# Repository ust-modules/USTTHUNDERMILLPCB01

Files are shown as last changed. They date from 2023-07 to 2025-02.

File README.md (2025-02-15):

# THUNDERMILL01 stator PCB

The PCB is part of [Electric field mill](https://github.com/UniversalScientificTechnologies/THUNDERMILL01).

<p float="left">
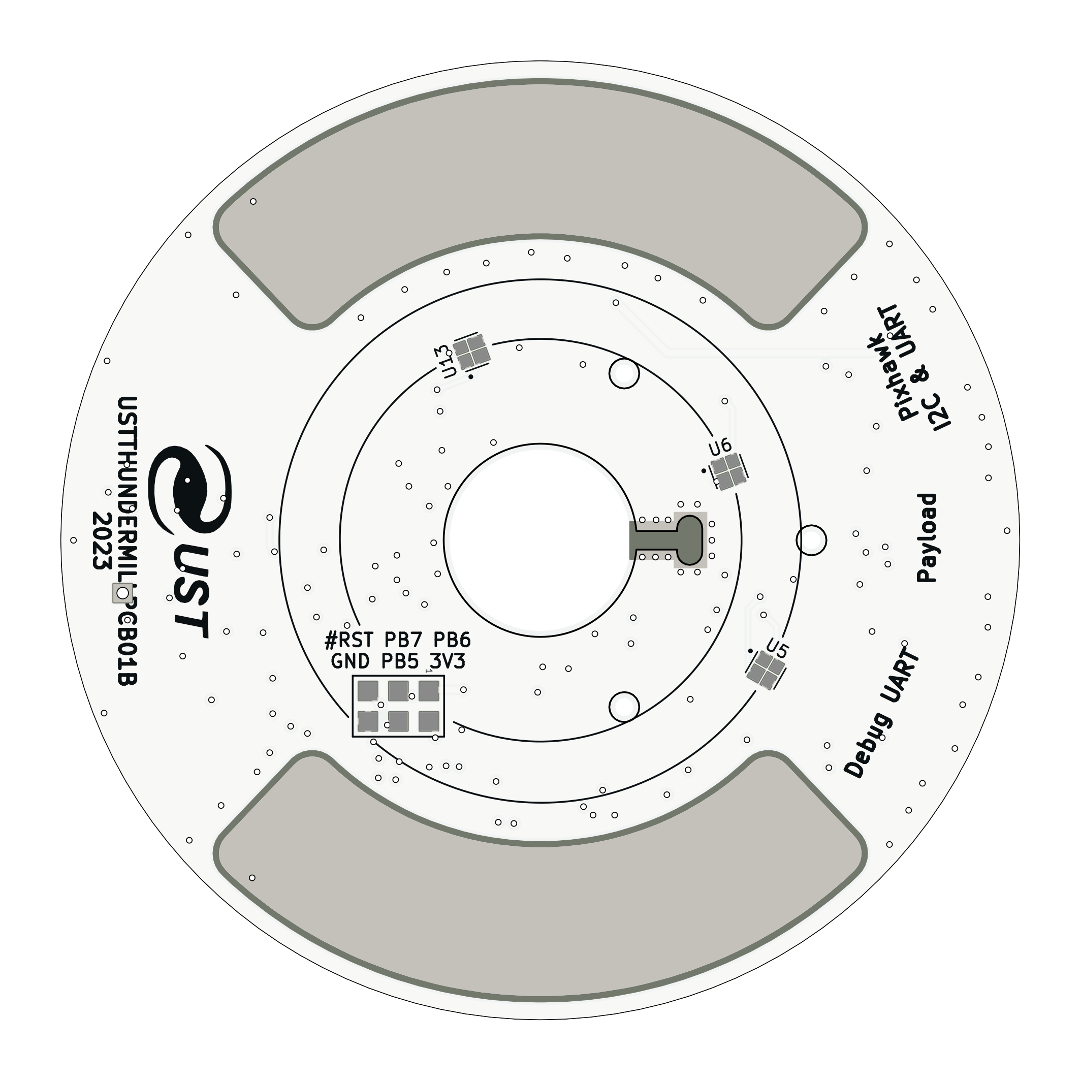
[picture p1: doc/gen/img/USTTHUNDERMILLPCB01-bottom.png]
  
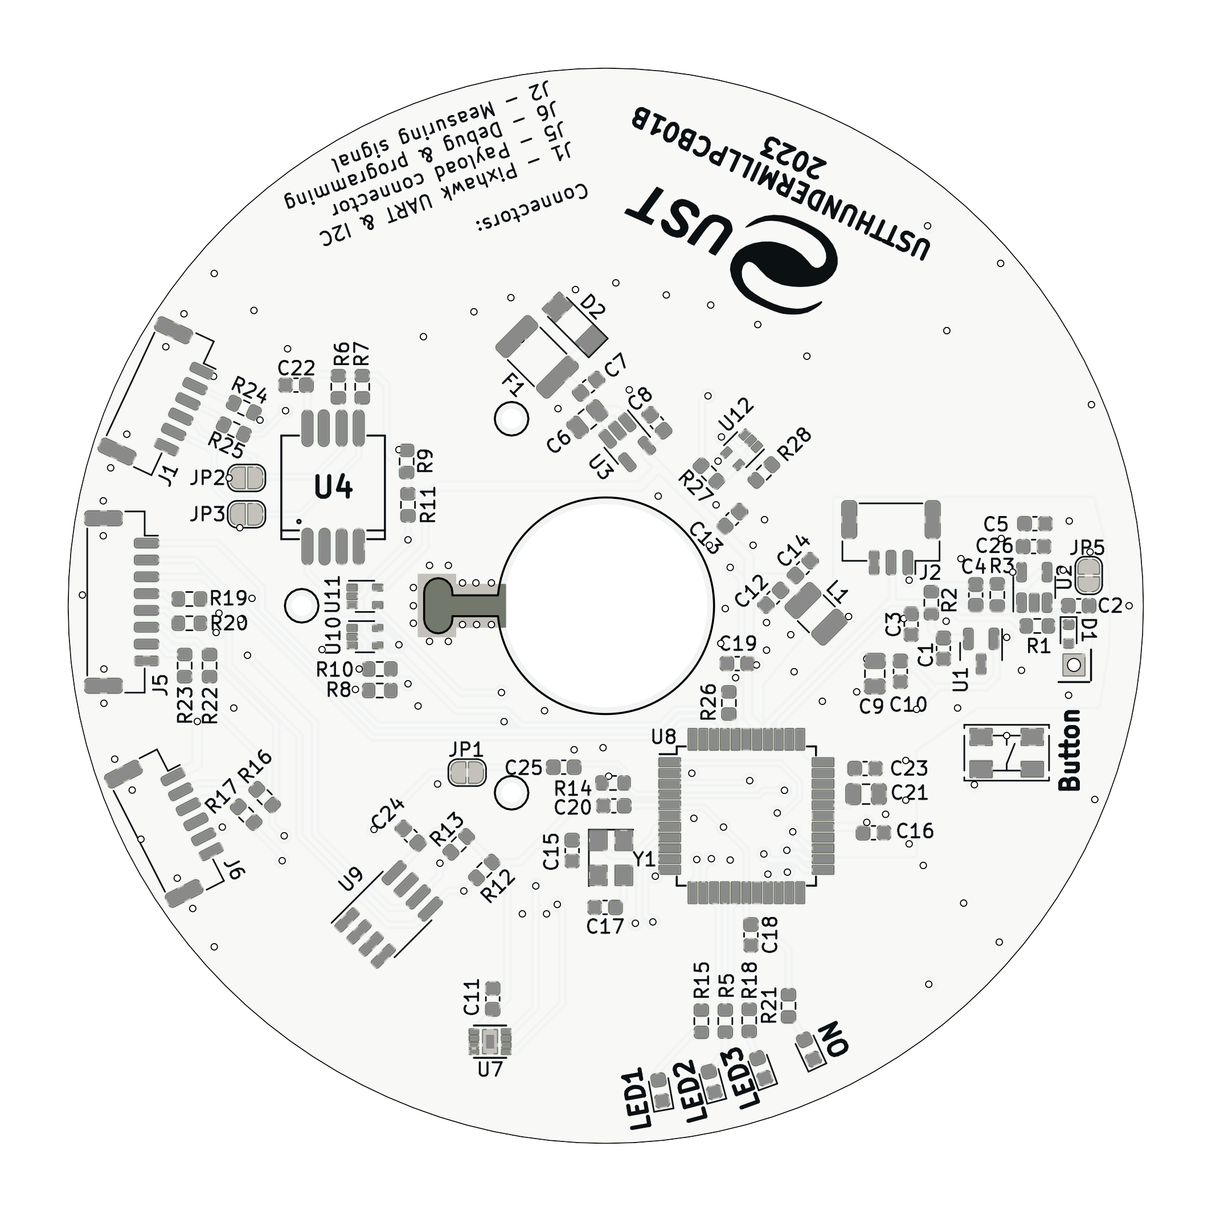
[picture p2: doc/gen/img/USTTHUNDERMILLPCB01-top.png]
   
</p>

The PCB consists analog front end, microcontroller and interface connectors.

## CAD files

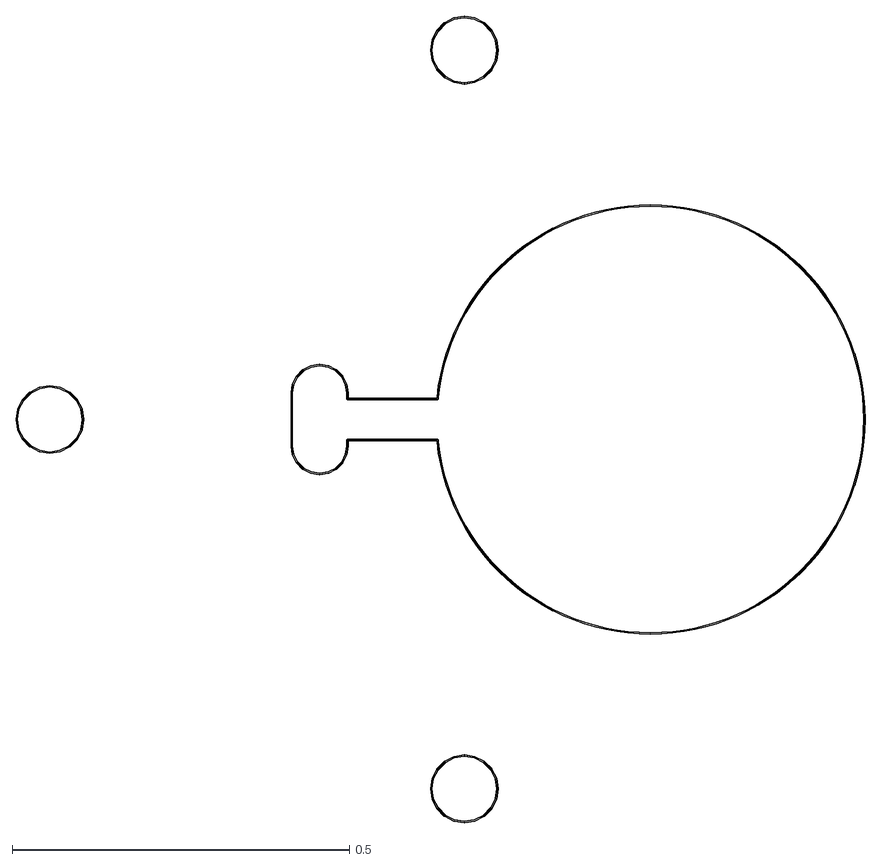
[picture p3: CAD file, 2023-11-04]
doc/gen/dxf/USTTHUNDERMILLPCB01-Edge_Mill.dxf
1.26 x 1.19

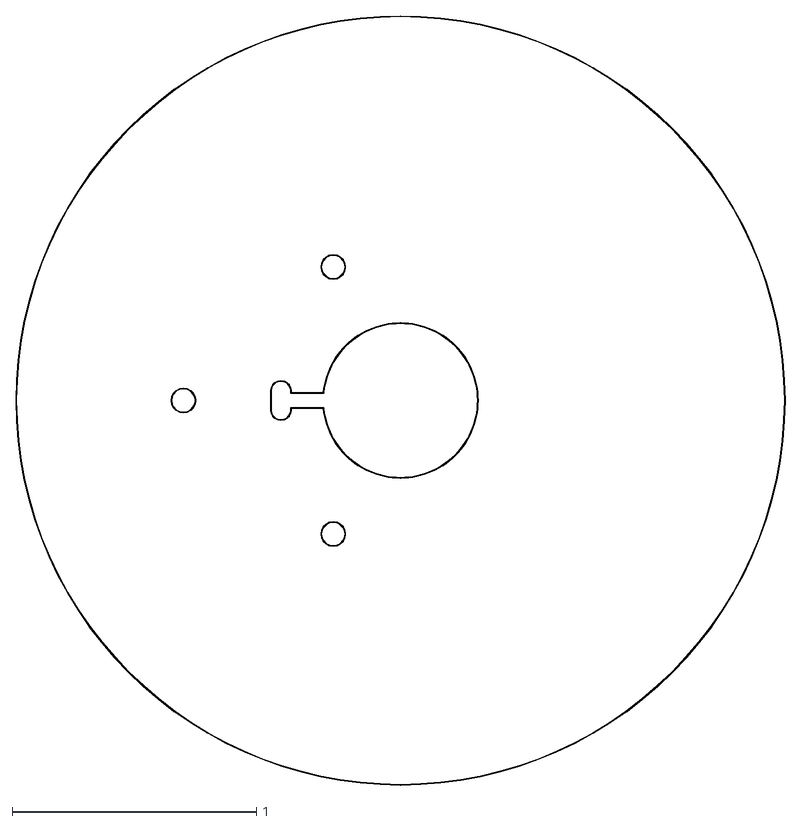
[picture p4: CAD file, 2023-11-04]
doc/gen/dxf/USTTHUNDERMILLPCB01-Edge_Cuts.dxf
3.15 x 3.15

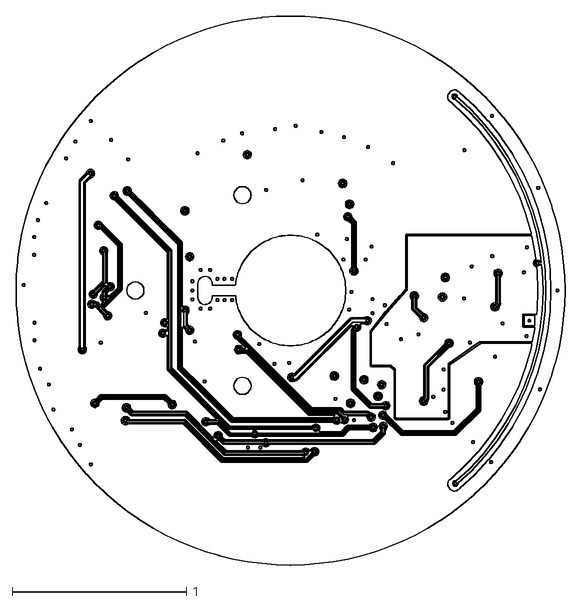
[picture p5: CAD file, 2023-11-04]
doc/gen/dxf/USTTHUNDERMILLPCB01-In1_Cu.dxf
3.15 x 3.15

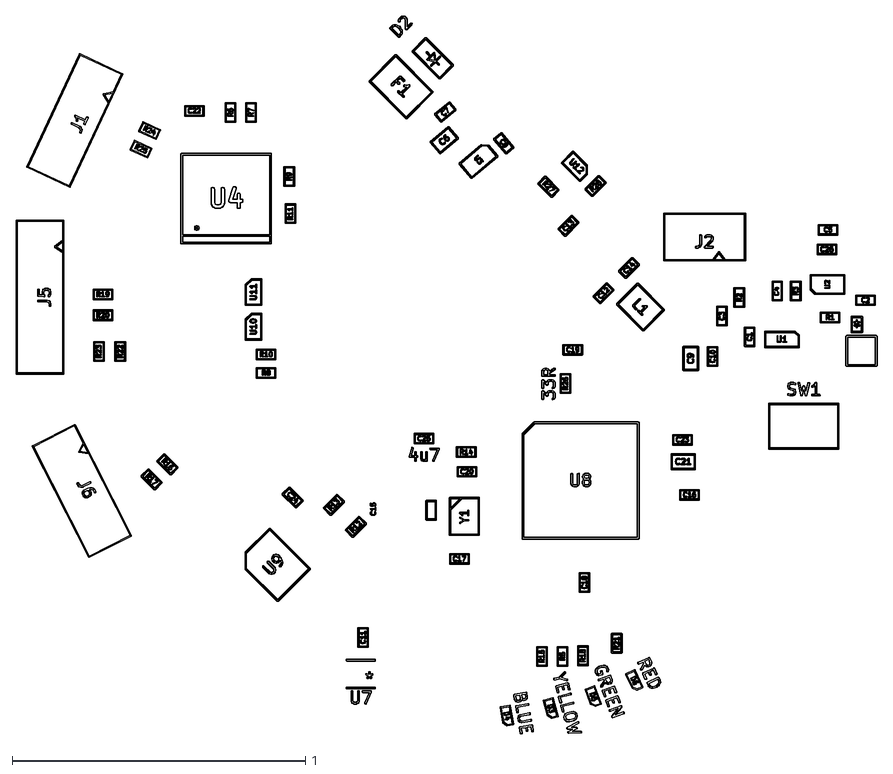
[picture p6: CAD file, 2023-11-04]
doc/gen/dxf/USTTHUNDERMILLPCB01-F_Fab.dxf
2.94 x 2.45

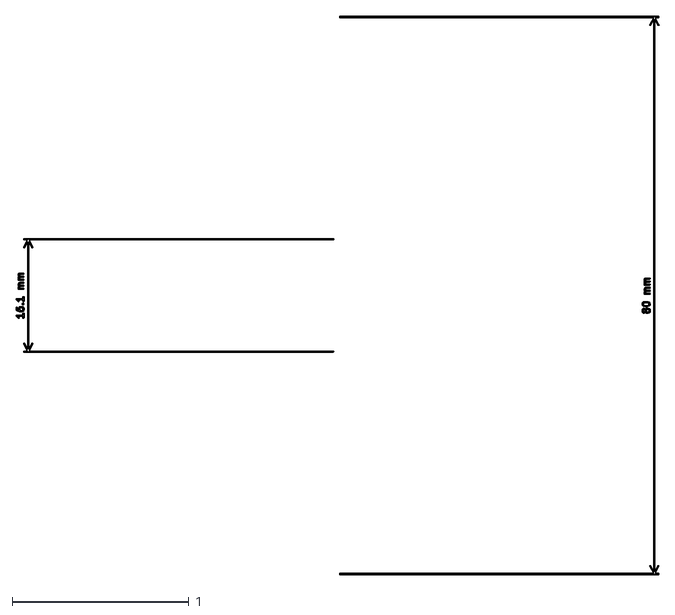
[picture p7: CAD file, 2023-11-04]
doc/gen/dxf/USTTHUNDERMILLPCB01-User_Comments.dxf
3.64 x 3.16

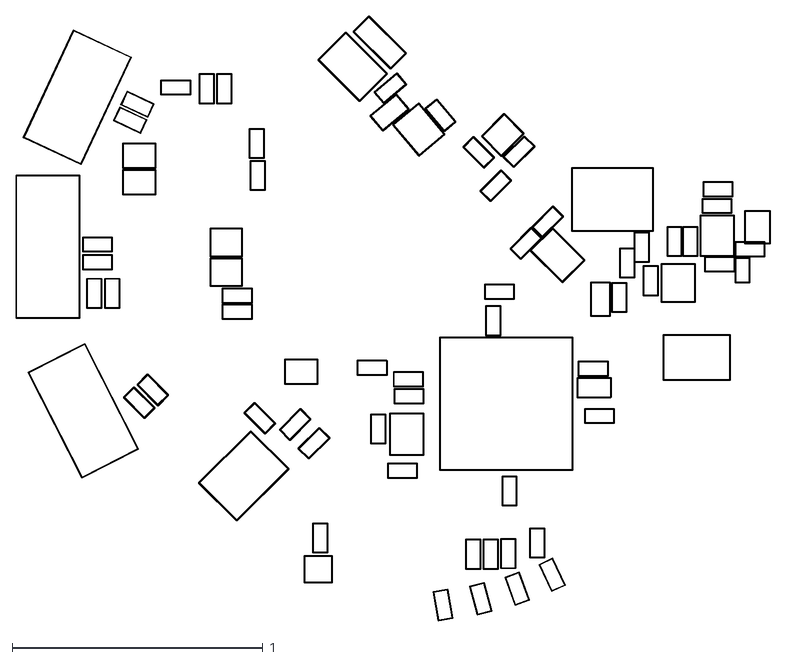
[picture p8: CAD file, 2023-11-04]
doc/gen/dxf/USTTHUNDERMILLPCB01-F_Courtyard.dxf
3.01 x 2.41

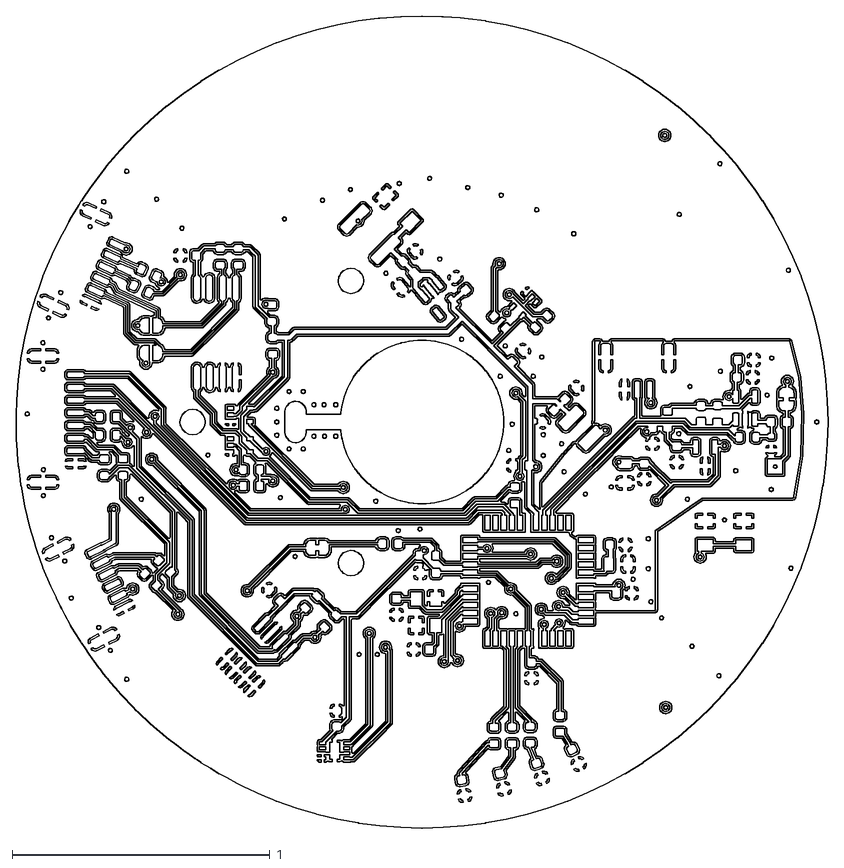
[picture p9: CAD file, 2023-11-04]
doc/gen/dxf/USTTHUNDERMILLPCB01-F_Cu.dxf
3.15 x 3.15

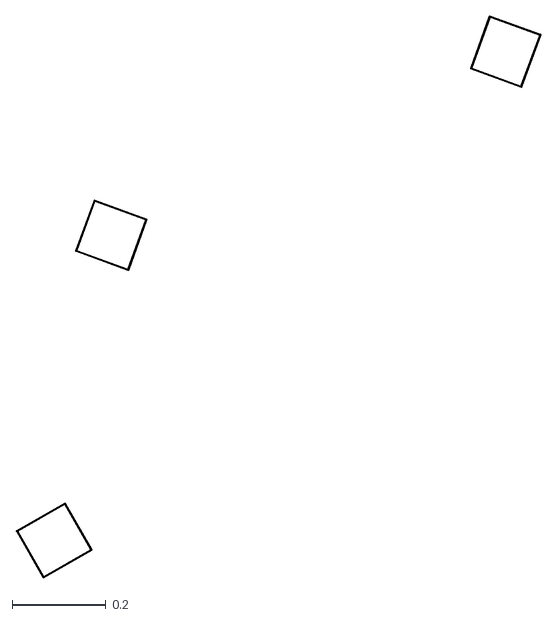
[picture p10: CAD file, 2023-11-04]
doc/gen/dxf/USTTHUNDERMILLPCB01-B_Courtyard.dxf
1.12 x 1.20

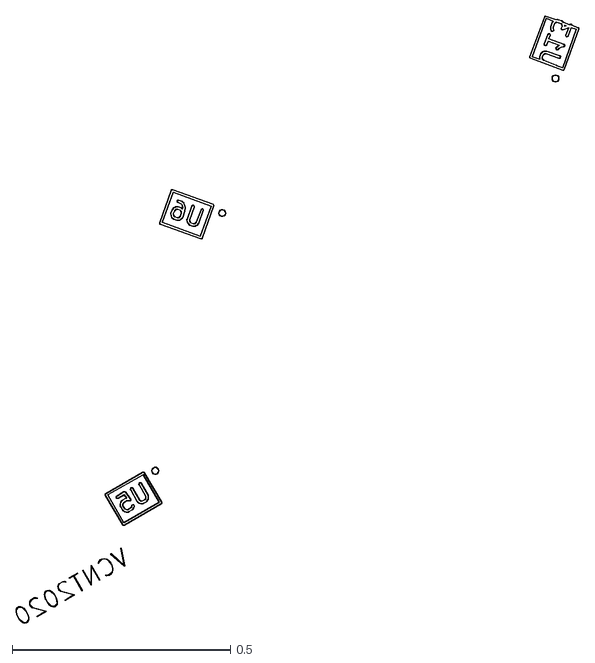
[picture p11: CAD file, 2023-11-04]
doc/gen/dxf/USTTHUNDERMILLPCB01-B_Fab.dxf
1.29 x 1.39

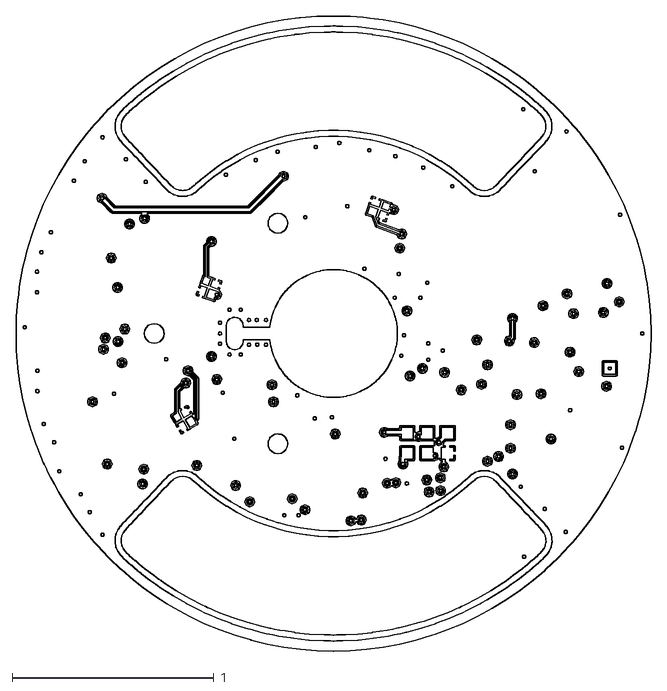
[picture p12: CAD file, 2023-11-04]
doc/gen/dxf/USTTHUNDERMILLPCB01-B_Cu.dxf
3.15 x 3.15

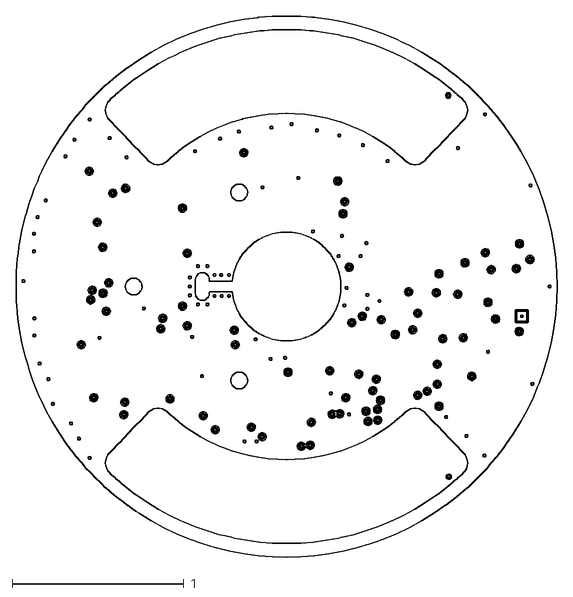
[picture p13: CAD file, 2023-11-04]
doc/gen/dxf/USTTHUNDERMILLPCB01-In2_Cu.dxf
3.15 x 3.15

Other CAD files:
doc/gen/dxf/USTTHUNDERMILLPCB01-B_Silkscreen.dxf
doc/gen/dxf/USTTHUNDERMILLPCB01-F_Silkscreen.dxf

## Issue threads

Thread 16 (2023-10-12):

Odolnost zarizeni proti vlhkosti

kakl, 2023-10-12:
Odpor R1 kondenzator C2 a D1 by bylo vhodne mit ve velikosti minimalne 805, lepe 1206.
Mely by zde byt take vetsi izolacni vzdalenosti.

Abych mohl snizit sense resistor R1 na 2M2, upravil jsem zesileni z 5,5x na 22x pomoci R2=470.

kakl, 2023-10-12:
uz je videt trochu sum od motoru, mozna by stacilo zesileni 18x

kakl, 2023-10-12:
nebo zvysit C4

kakl, 2023-10-12:
C3 lze zvednout az na M1

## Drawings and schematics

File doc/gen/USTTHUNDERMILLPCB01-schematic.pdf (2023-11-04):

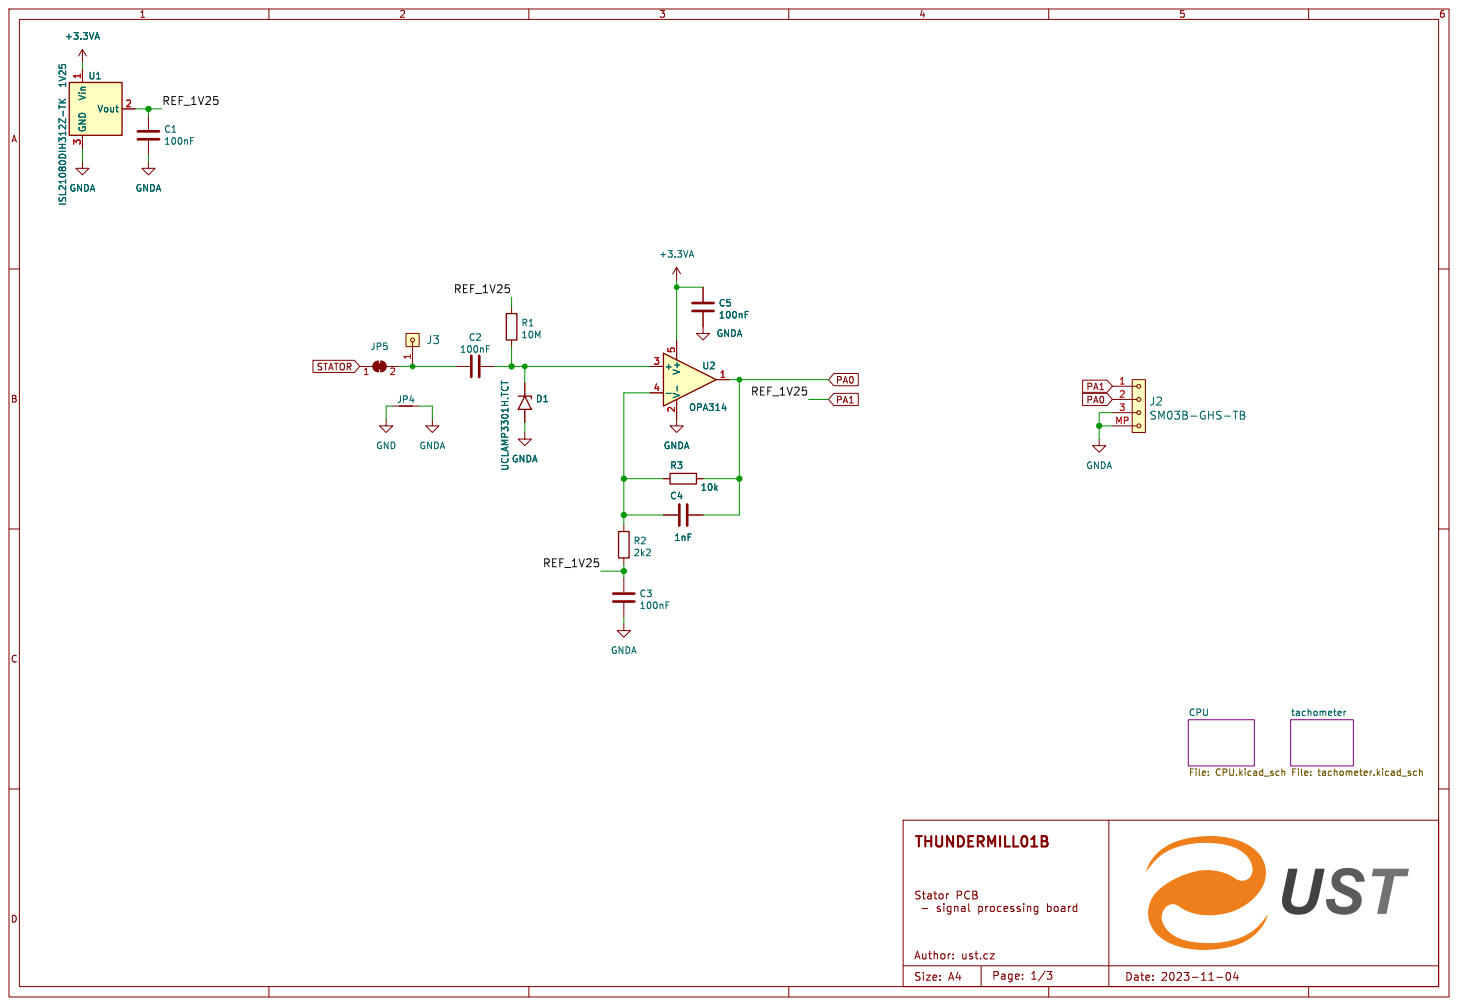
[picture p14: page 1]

tachometer File: tachometer.kicad_sch CPU

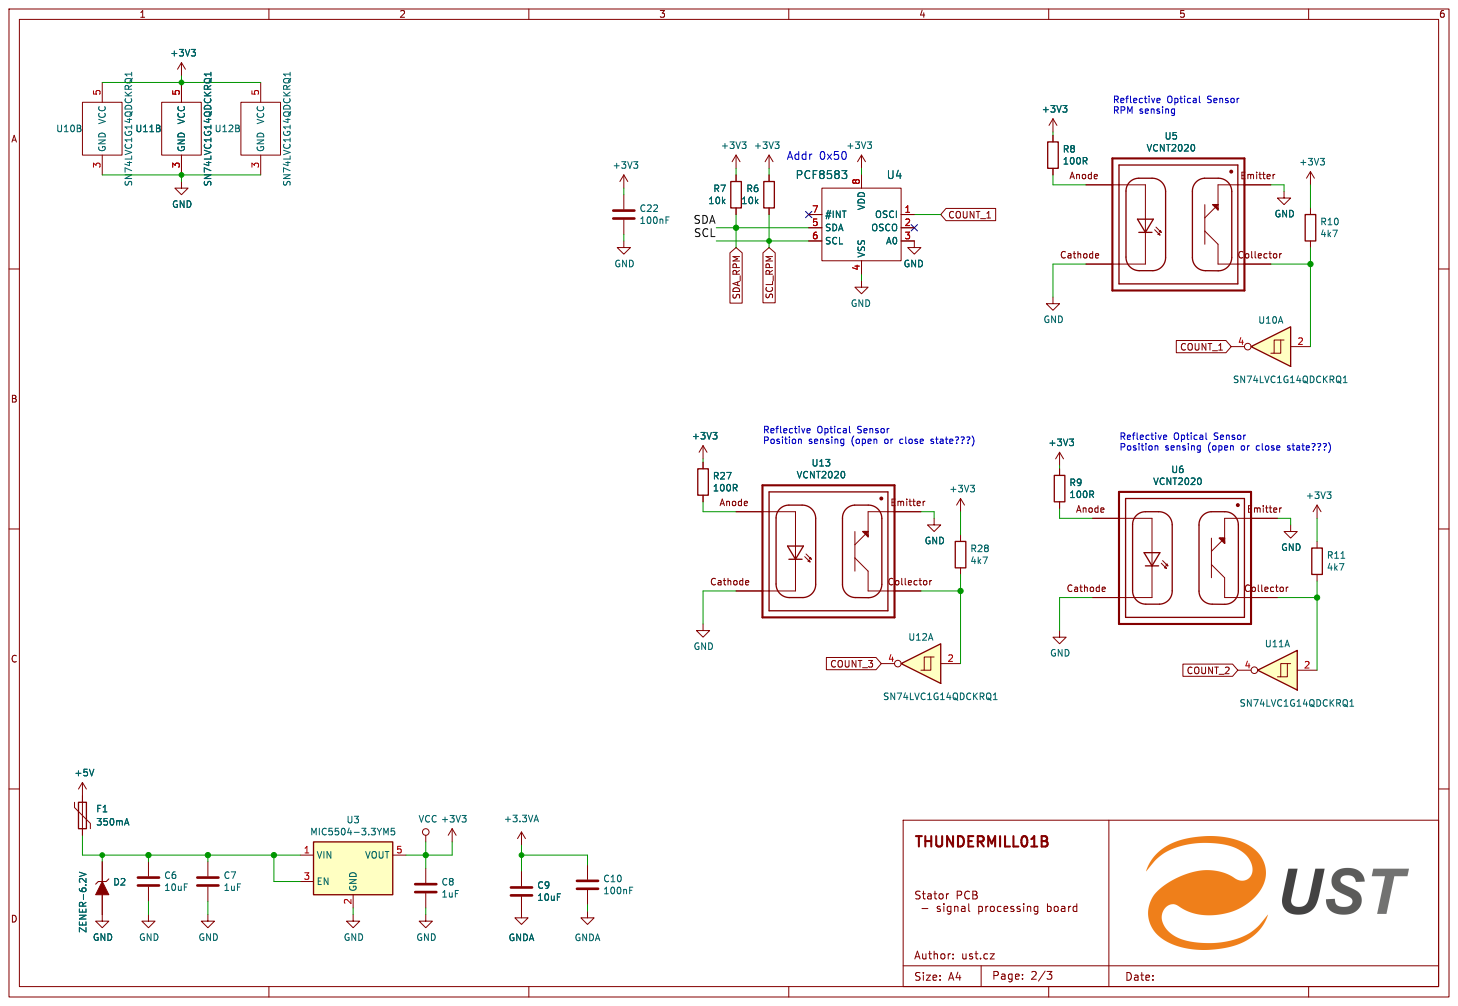
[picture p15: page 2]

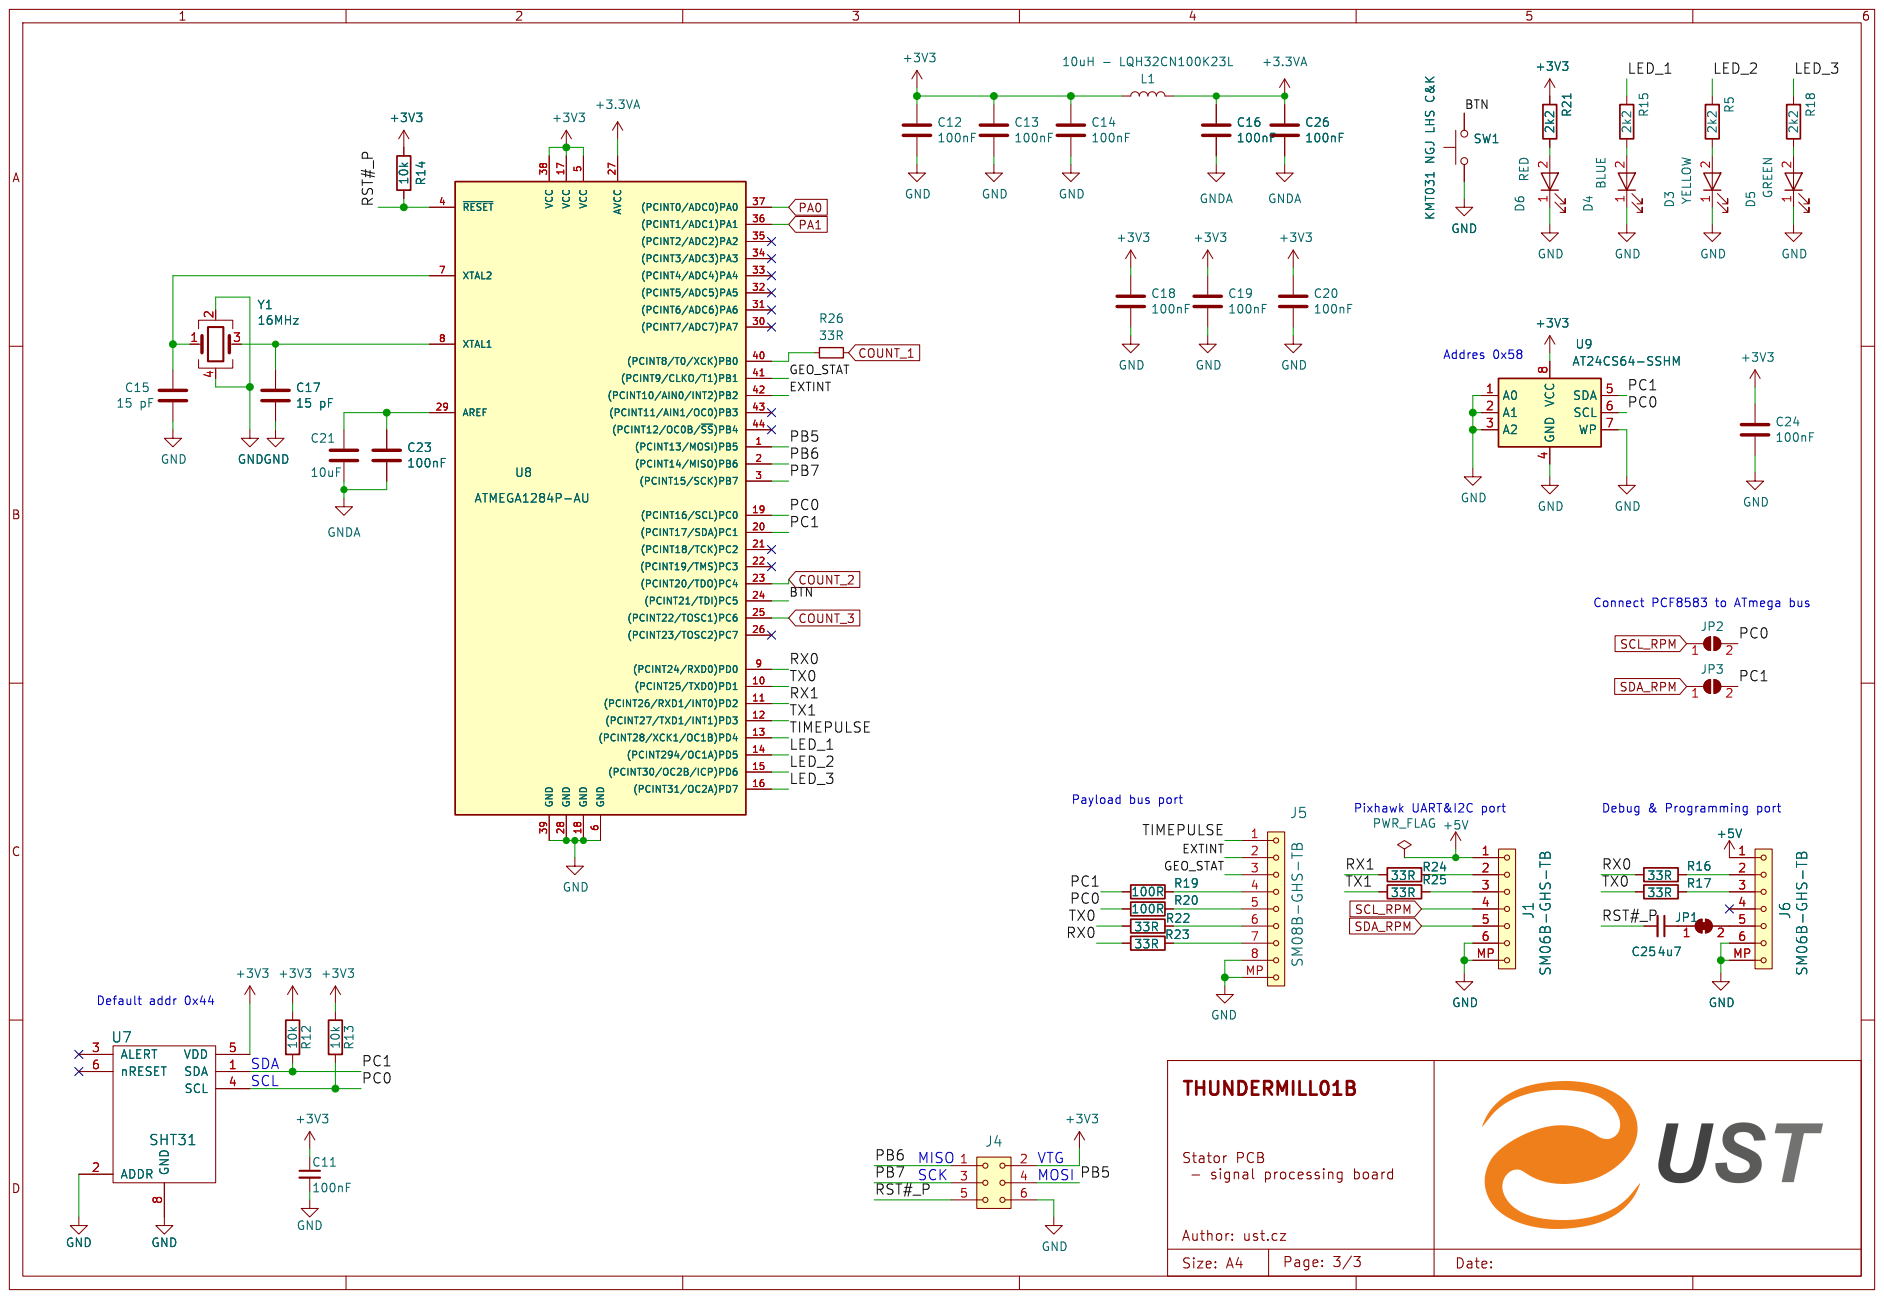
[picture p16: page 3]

4 SDA 5 SCL 6 WP 7 VCC

Payload bus port U8 ATMEGA1284P-AU

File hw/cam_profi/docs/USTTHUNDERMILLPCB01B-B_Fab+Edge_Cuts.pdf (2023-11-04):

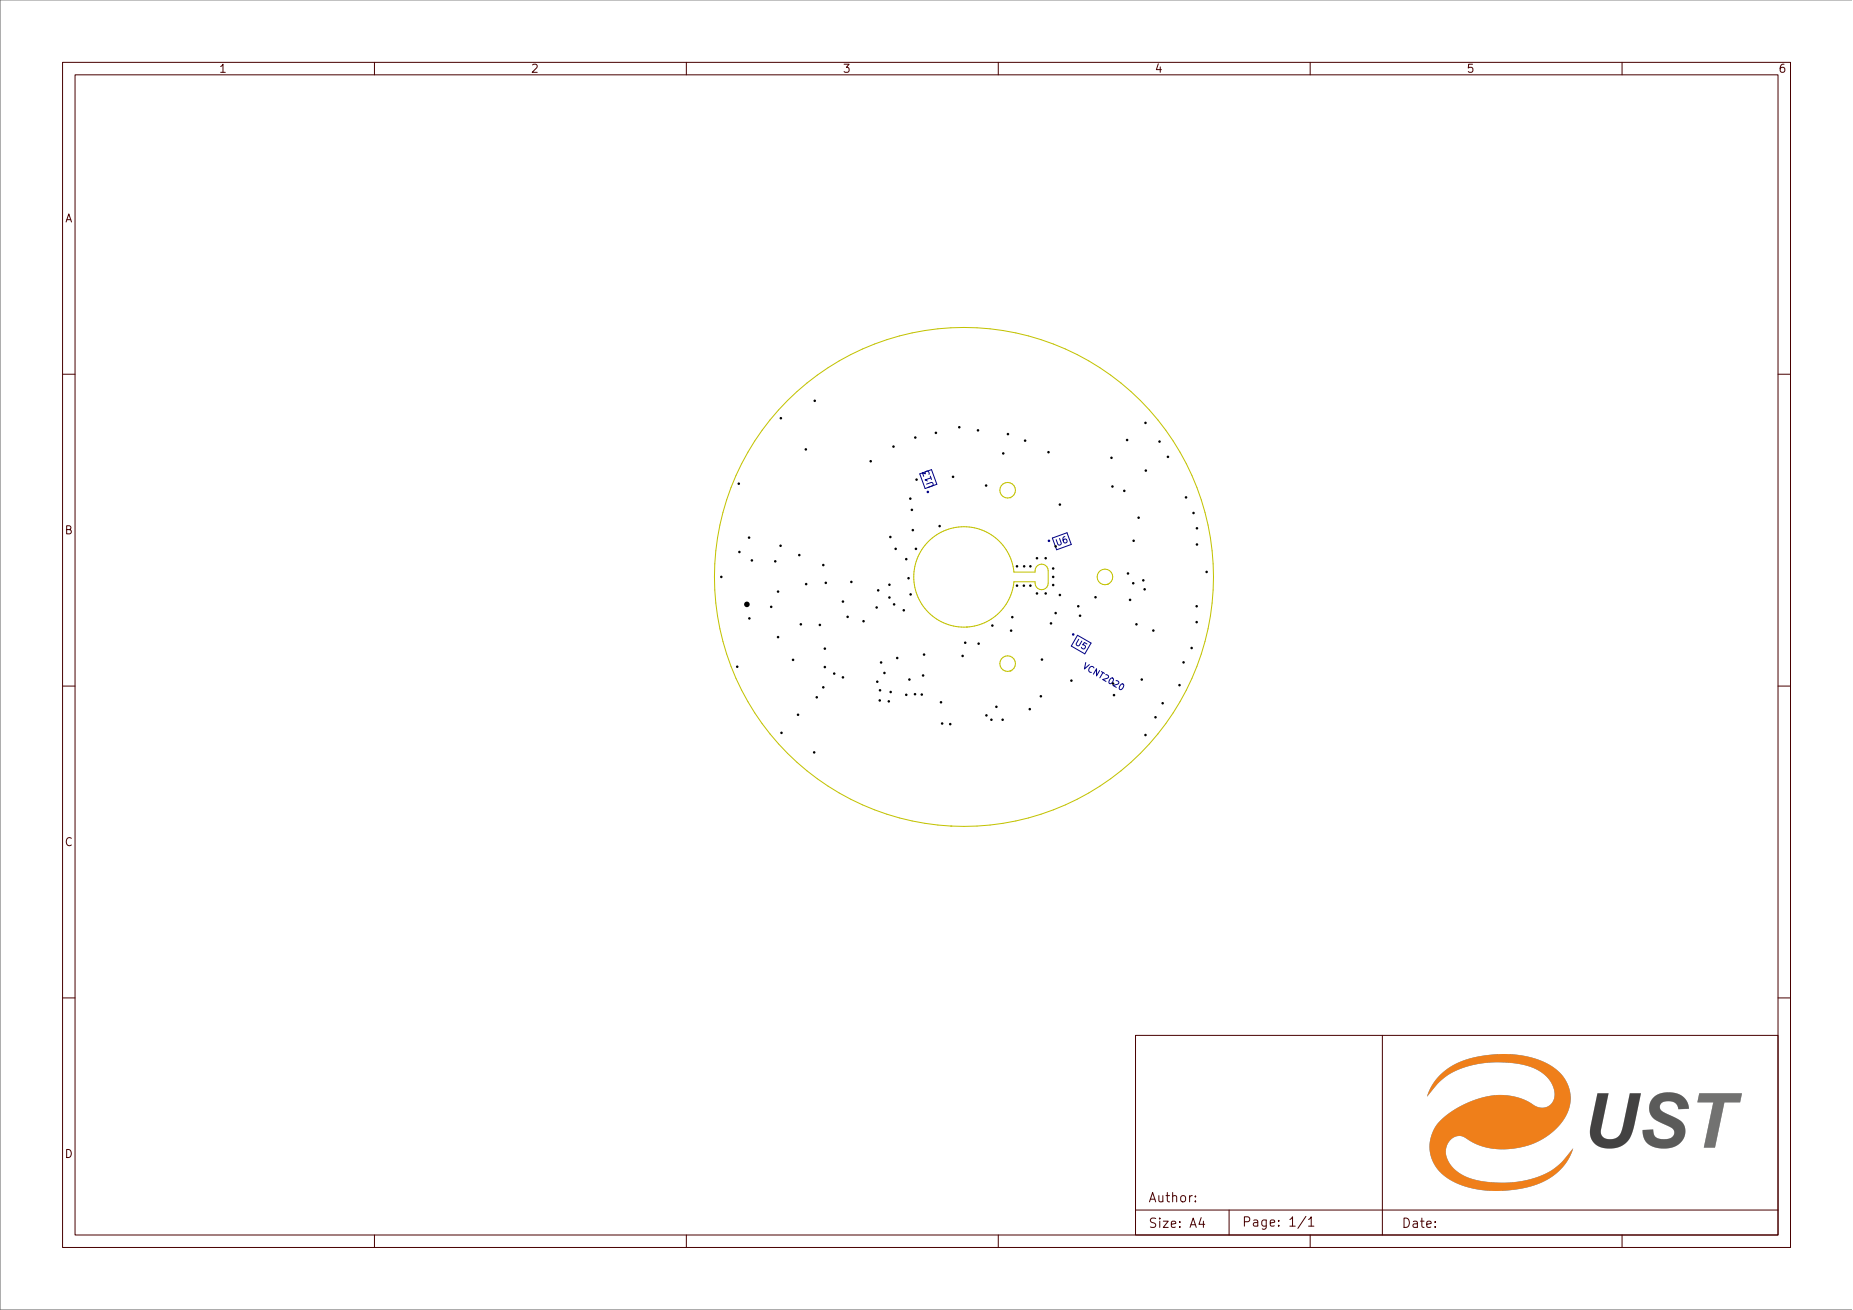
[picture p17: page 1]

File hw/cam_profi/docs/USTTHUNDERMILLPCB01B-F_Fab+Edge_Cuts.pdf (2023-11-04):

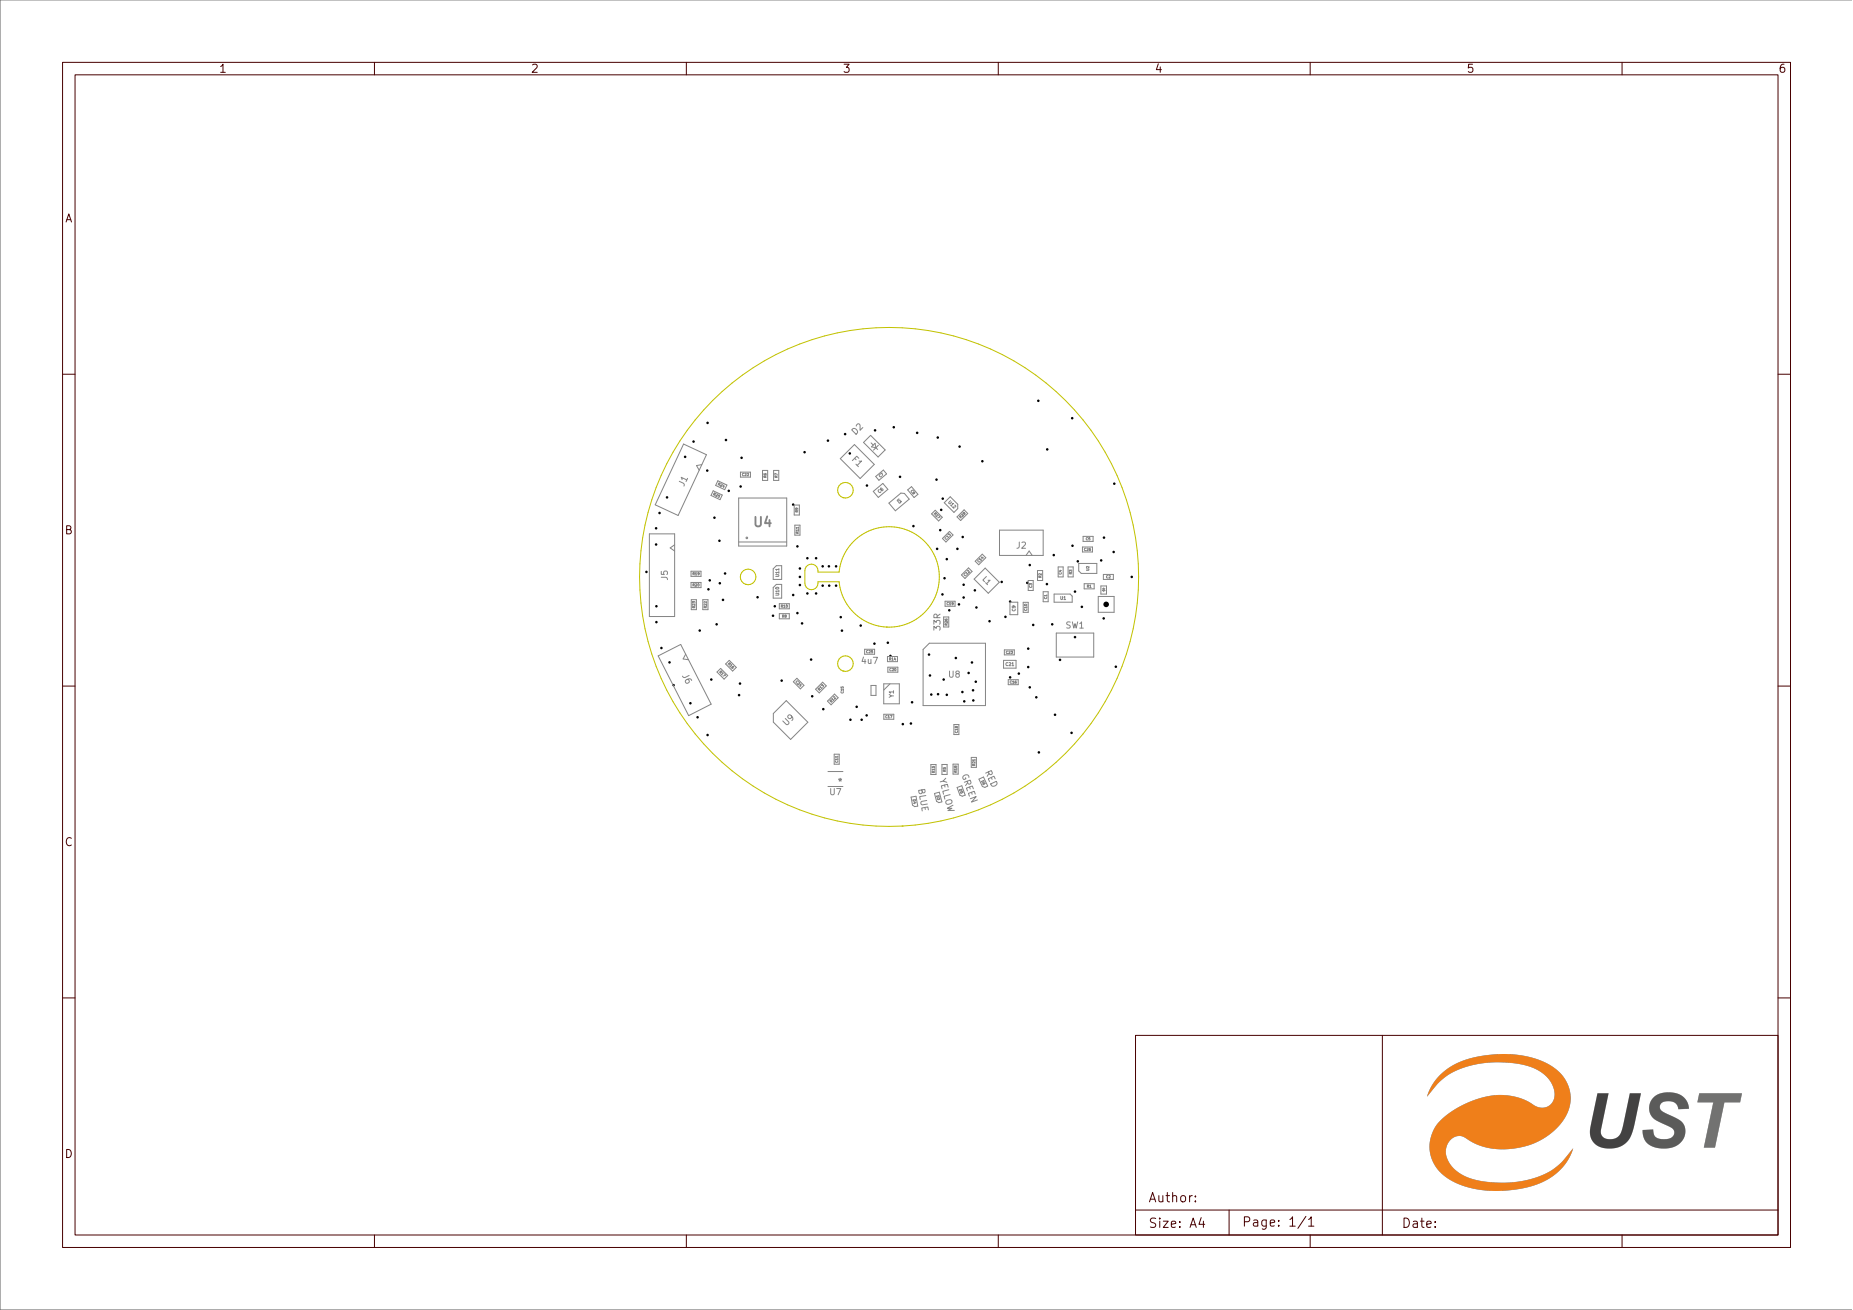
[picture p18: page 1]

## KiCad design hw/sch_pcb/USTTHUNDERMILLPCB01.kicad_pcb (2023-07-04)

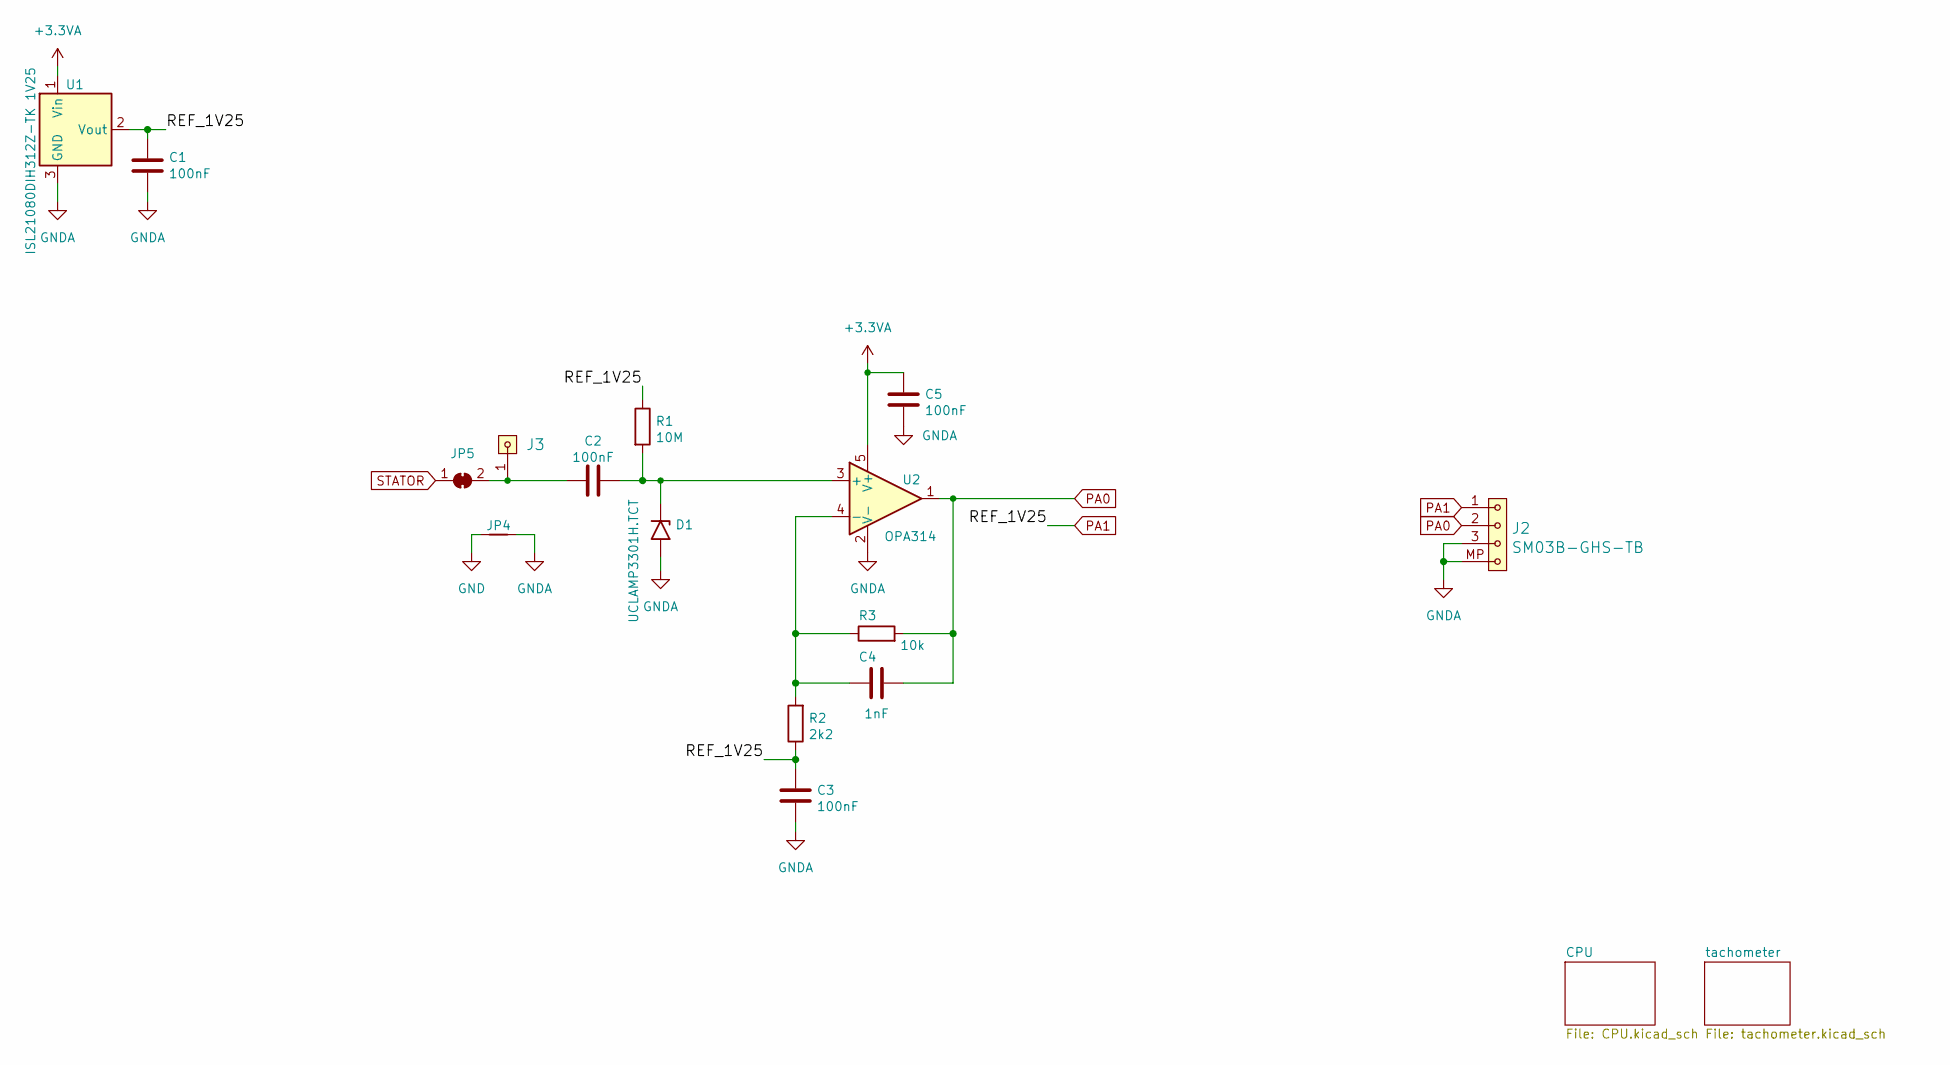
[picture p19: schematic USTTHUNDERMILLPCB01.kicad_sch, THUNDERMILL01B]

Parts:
C1, C2, C3, C5: 100nF; C_0603_1608Metric
C4: 1nF; C_0603_1608Metric
D1: UCLAMP3301H.TCT; D_SOD-523
J2: SM03B-GHS-TB; JST_GH_SM03B-GHS-TB_1x03-1MP_P1.25mm_Horizontal
J3: HEADER_1x01; Straight_1x01
JP4: Jumper_2_Bridged; NetTie-2_SMD_Pad0.5mm
JP5: SolderJumper_2_Bridged; SolderJumper-2_P1.3mm_Bridged_RoundedPad1.0x1.5mm
R1: 10M; R_0603_1608Metric
R2: 2k2; R_0603_1608Metric
R3: 10k; R_0603_1608Metric
U1: ISL21080DIH312Z-TK 1V25; SOT-23
U2: OPA314; SOT-23-5

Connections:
+3.3VA: C5.2, U1.1 (Vin), U2.5 (V+); also elsewhere on the board
GND: JP4.1; also elsewhere on the board
GNDA: C1.2, C3.1, C5.1, D1.2 (A2), J2.3, J2.MP, JP4.2, U1.3 (GND), U2.2 (V-); also elsewhere on the board
unnamed: C2.2, D1.1 (A1), R1.2, U2.3 (+)
unnamed: C2.1, J3.1, JP5.2 (B)
unnamed: C4.1, R2.2, R3.1, U2.4 (-)
PA0: C4.2, J2.2, R3.2, U2.1; also elsewhere on the board
PA1: C1.1, C3.2, J2.1, R1.1, R2.1, U1.2 (Vout); also elsewhere on the board
STATOR: JP5.1 (A)

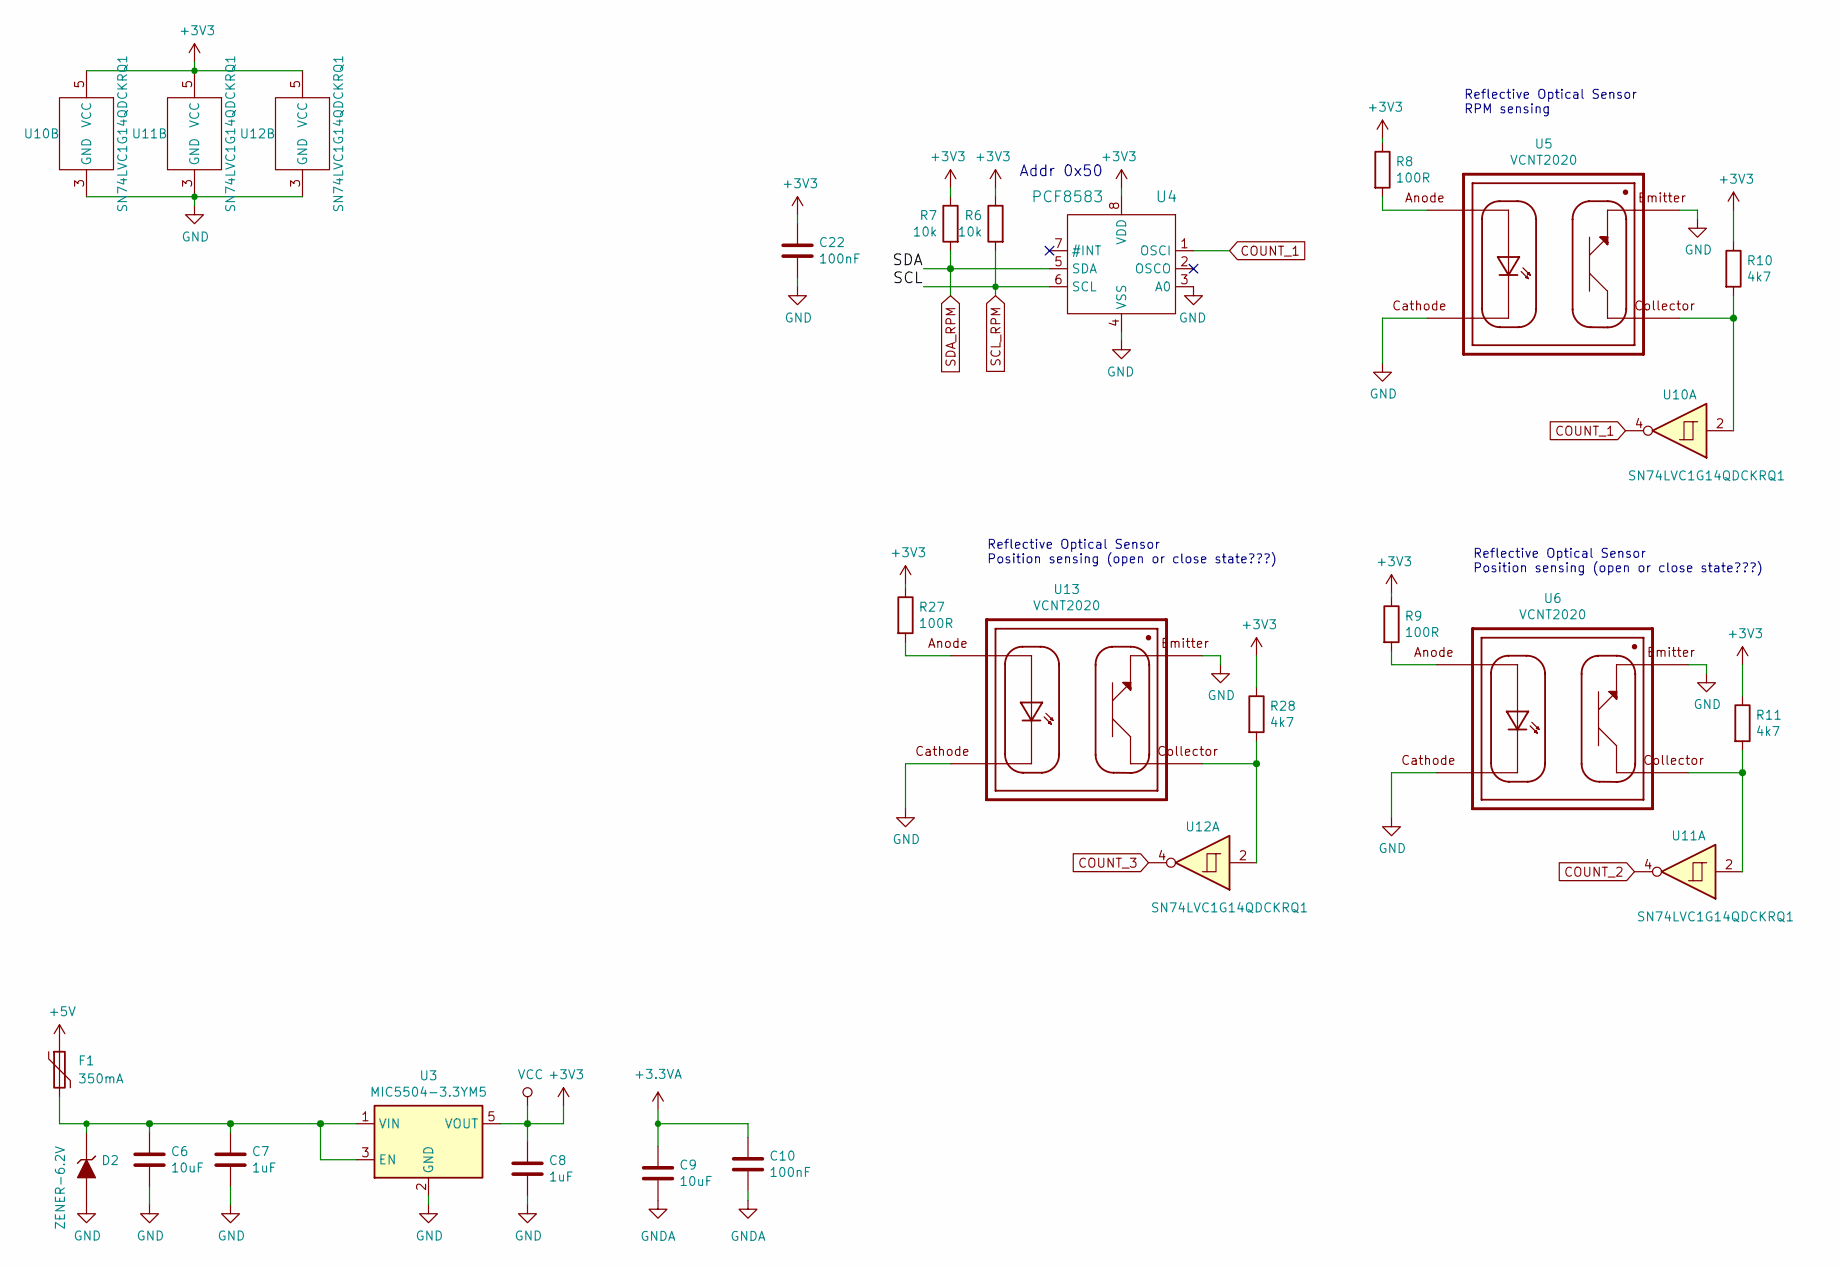
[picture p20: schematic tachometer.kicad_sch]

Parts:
C6, C9: 10uF; C_0805_2012Metric
C7, C8: 1uF; C_0603_1608Metric
C10, C22: 100nF; C_0603_1608Metric
D2: ZENER-6.2V; Diode-MiniMELF_Standard
F1: 350mA; Fuse_1812_4532Metric
R6, R7: 10k; R_0603_1608Metric
R8, R9, R27: 100R; R_0603_1608Metric
R10, R11, R28: 4k7; R_0603_1608Metric
U3: MIC5504-3.3YM5; SOT-23-5
U4: PCF8583; SOT176-1
U5, U6, U13: VCNT2020; XDCR_VCNT2020
U10, U11, U12: SN74LVC1G14QDCKRQ1; SOT-353_SC-70-5

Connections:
+3.3VA: C9.1, C10.1; also elsewhere on the board
+3V3: C8.1, C22.1, R6.1, R7.1, R8.1, R9.1, R10.1, R11.1, R27.1, R28.1, U3.5 (VOUT), U4.8 (VDD), U10.5 (VCC), U11.5 (VCC), U12.5 (VCC); also elsewhere on the board
+5V: F1.1; also elsewhere on the board
COUNT_1: U4.1 (OSCI), U10.4; also elsewhere on the board
COUNT_2: U11.4; also elsewhere on the board
COUNT_3: U12.4; also elsewhere on the board
GND: C6.2, C7.2, C8.2, C22.2, D2.2 (A), U3.2 (GND), U4.3 (A0), U4.4 (VSS), U5.1, U5.4, U6.1, U6.4, U10.3 (GND), U11.3 (GND), U12.3 (GND), U13.1, U13.4; also elsewhere on the board
GNDA: C9.2, C10.2; also elsewhere on the board
unnamed: C6.1, C7.1, D2.1 (K), F1.2, U3.1 (VIN), U3.3 (EN)
unnamed: R8.2, U5.3
unnamed: R9.2, U6.3
unnamed: R10.2, U5.2, U10.2
unnamed: R11.2, U6.2, U11.2
unnamed: R27.2, U13.3
unnamed: R28.2, U12.2, U13.2
SCL_RPM: R6.2, U4.6 (SCL); also elsewhere on the board
SDA_RPM: R7.2, U4.5 (SDA); also elsewhere on the board

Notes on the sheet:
Addr 0x50
Reflective Optical Sensor Position sensing (open or close state???)
Reflective Optical Sensor RPM sensing

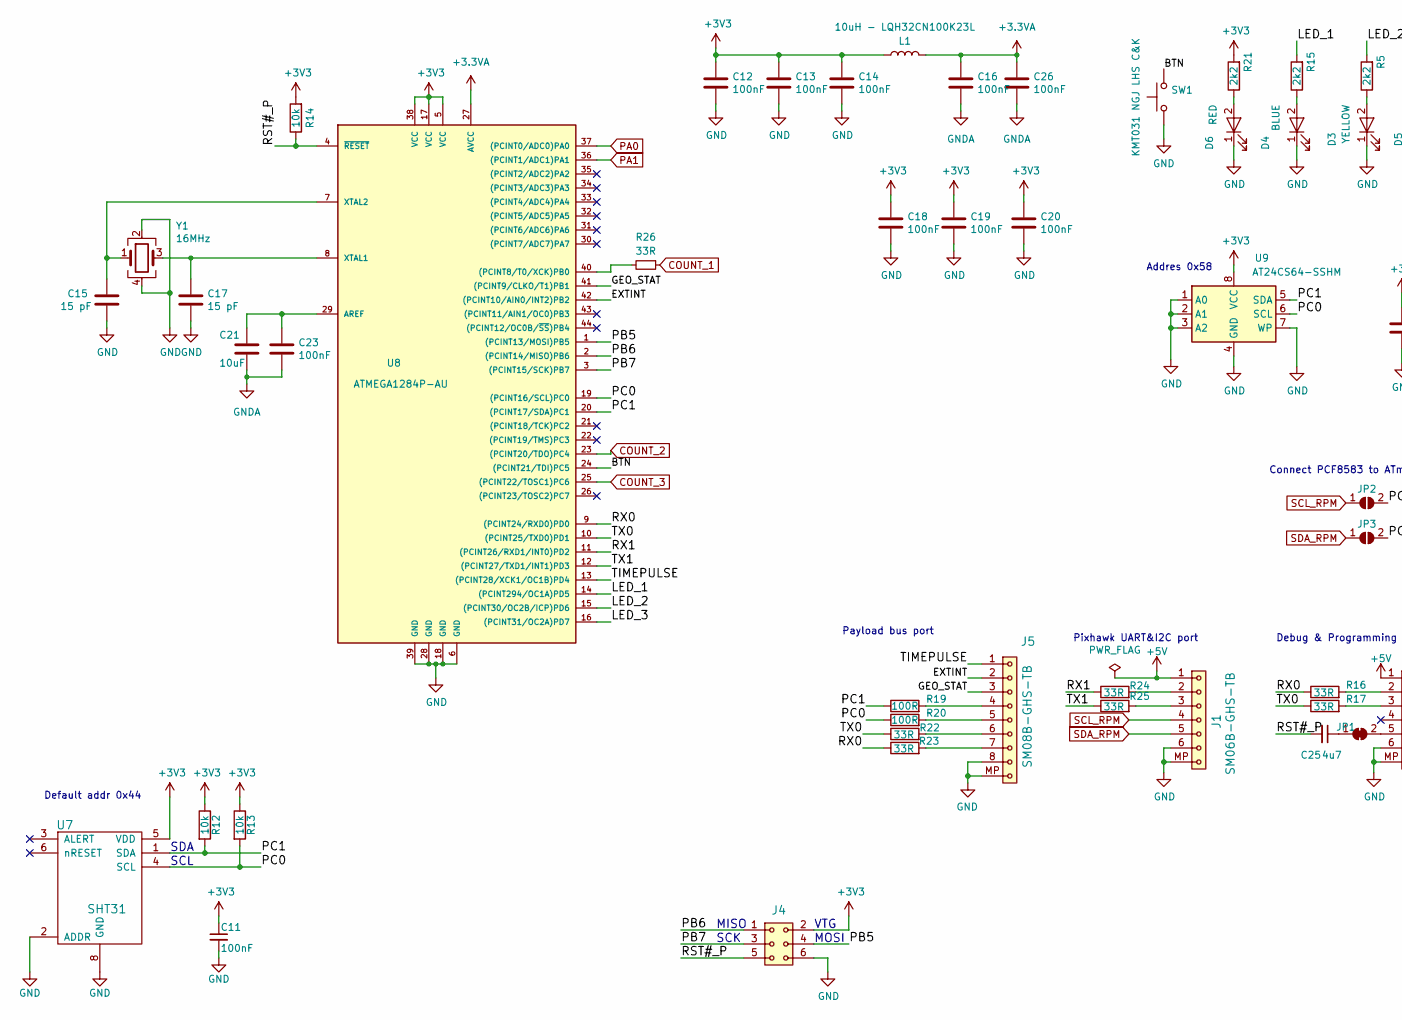
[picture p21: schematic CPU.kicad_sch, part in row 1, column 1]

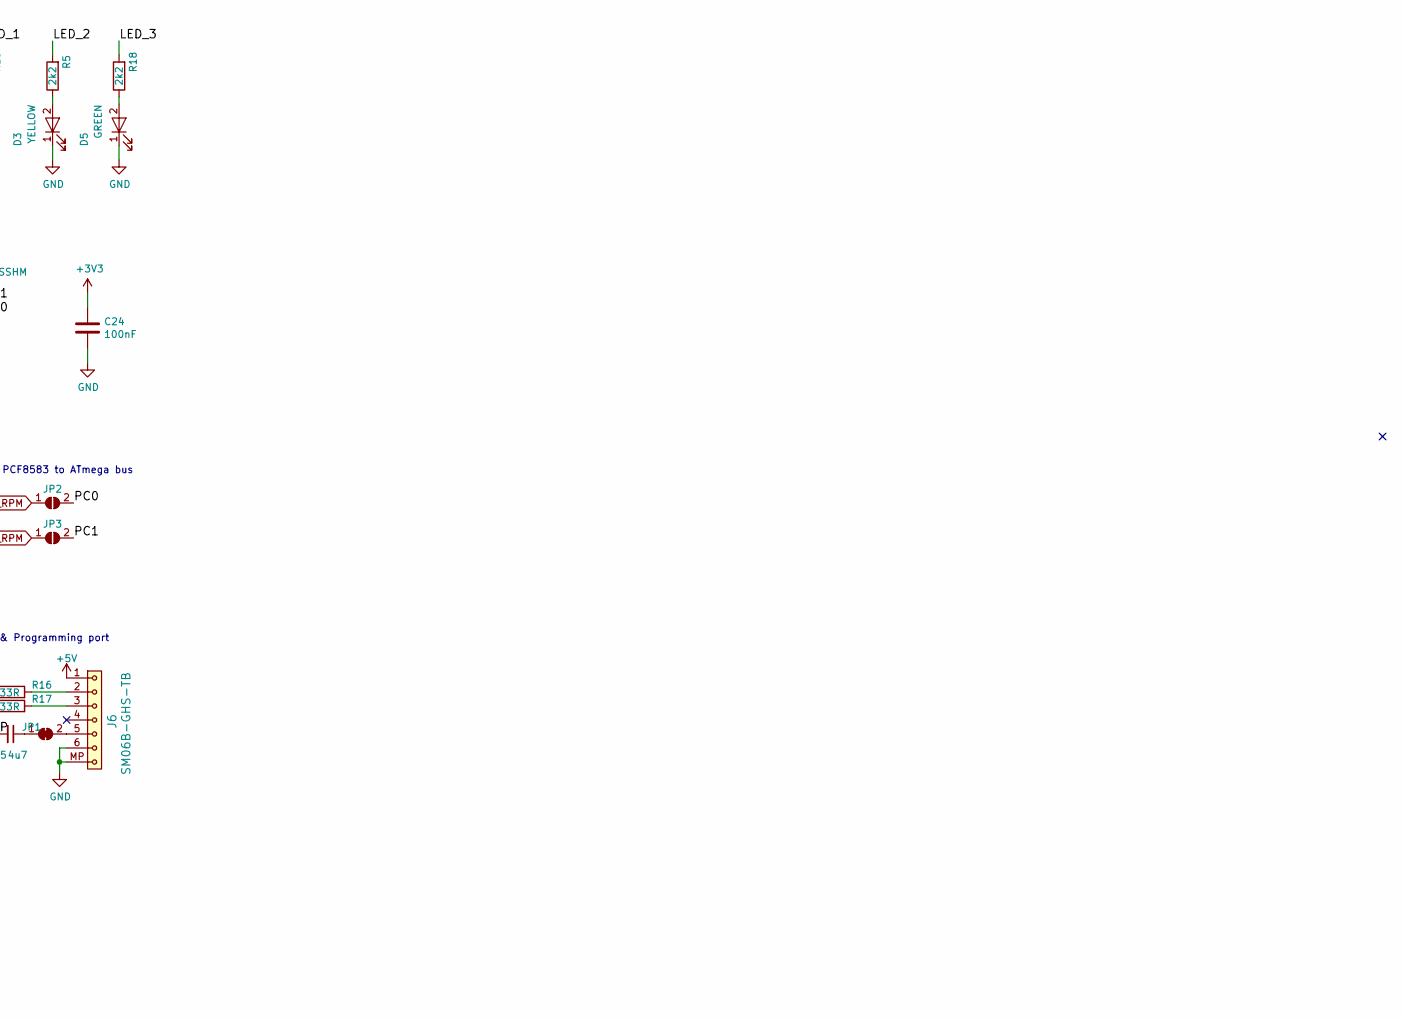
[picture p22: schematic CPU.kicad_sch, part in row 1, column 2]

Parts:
C11, C12, C13, C14, C16, C18, C19, C20, C23, C24, C26: 100nF; C_0603_1608Metric
C15, C17: 15 pF; C_0603_1608Metric
C21: 10uF; C_0805_2012Metric
C25: 4u7
D3: YELLOW; LED_0603_1608Metric
D4: BLUE; LED_0603_1608Metric
D5: GREEN; LED_0603_1608Metric
D6: RED; LED_0603_1608Metric
J1, J6: SM06B-GHS-TB; JST_GH_SM06B-GHS-TB_1x06-1MP_P1.25mm_Horizontal
J4: HEADER_2x03; SMD_2x03
J5: SM08B-GHS-TB; JST_GH_SM08B-GHS-TB_1x08-1MP_P1.25mm_Horizontal
JP1: SolderJumper_2_Bridged
JP2, JP3: SolderJumper_2_Open
L1: 10uH - LQH32CN100K23L; L_1210_3225Metric
R5, R15, R18, R21: 2k2; R_0603_1608Metric
R12, R13, R14: 10k; R_0603_1608Metric
R16, R17, R22, R23, R24, R25: 33R; R_0603_1608Metric
R19, R20: 100R; R_0603_1608Metric
R26: 33R
SW1: KMT031 NGJ LHS C&K
U7: SHT31; DFN-8-1EP_2.4x2.4mm_Pitch0.5mm
U8: ATMEGA1284P-AU; TQFP-44_10x10mm_P0.8mm
U9: AT24CS64-SSHM; SOIC-8_3.9x4.9mm_P1.27mm
Y1: 16MHz; Crystal SMD CFPX-180

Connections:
+3.3VA: C16.1, C26.1, L1.2, U8.27 (AVCC); also elsewhere on the board
+3V3: C11.1, C12.1, C13.1, C14.1, C18.1, C19.1, C20.1, C24.1, J4.2, L1.1, R12.1, R13.1, R14.2, R21.2, U7.5 (VDD), U8.5 (VCC), U8.17 (VCC), U8.38 (VCC), U9.8 (VCC); also elsewhere on the board
+5V: J1.1, J6.1; also elsewhere on the board
/CPU/BTN: SW1.2, U8.24 ((PCINT21/TDI)PC5)
/CPU/EXTINT: J5.2, U8.42 ((PCINT10/AIN0/INT2)PB2)
/CPU/GEO_STAT: J5.3, U8.41 ((PCINT9/CLKO/T1)PB1)
/CPU/LED_1: R15.2, U8.14 ((PCINT294/OC1A)PD5)
/CPU/LED_2: R5.2, U8.15 ((PCINT30/OC2B/ICP)PD6)
/CPU/LED_3: R18.2, U8.16 ((PCINT31/OC2A)PD7)
/CPU/PB5: J4.4, U8.1 ((PCINT13/MOSI)PB5)
/CPU/PB6: J4.1, U8.2 ((PCINT14/MISO)PB6)
/CPU/PB7: J4.3, U8.3 ((PCINT15/SCK)PB7)
/CPU/PC0: JP2.2 (B), R13.2, R20.1, U7.4 (SCL), U8.19 ((PCINT16/SCL)PC0), U9.6 (SCL)
/CPU/PC1: JP3.2 (B), R12.2, R19.1, U7.1 (SDA), U8.20 ((PCINT17/SDA)PC1), U9.5 (SDA)
/CPU/RST#_P: C25.2, J4.5, R14.1, U8.4 (~RESET)
/CPU/RX0: R16.1, R23.1, U8.9 ((PCINT24/RXD0)PD0)
/CPU/RX1: R24.1, U8.11 ((PCINT26/RXD1/INT0)PD2)
/CPU/TIMEPULSE: J5.1, U8.13 ((PCINT28/XCK1/OC1B)PD4)
/CPU/TX0: R17.1, R22.1, U8.10 ((PCINT25/TXD0)PD1)
/CPU/TX1: R25.1, U8.12 ((PCINT27/TXD1/INT1)PD3)
COUNT_1: R26.1; also elsewhere on the board
COUNT_2: U8.23 ((PCINT20/TDO)PC4); also elsewhere on the board
COUNT_3: U8.25 ((PCINT22/TOSC1)PC6); also elsewhere on the board
GND: C11.2, C12.2, C13.2, C14.2, C15.2, C17.2, C18.2, C19.2, C20.2, C24.2, D3.1 (K), D4.1 (K), D5.1 (K), D6.1 (K), J1.6, J1.MP, J4.6, J5.8, J5.MP, J6.6, J6.MP, SW1.1, U7.2 (ADDR), U7.7 (GND), U7.8 (GND), U7.9 (GND), U8.6 (GND), U8.18 (GND), U8.28 (GND), U8.39 (GND), U9.1 (A0), U9.2 (A1), U9.3 (A2), U9.4 (GND), U9.7 (WP), Y1.2, Y1.4; also elsewhere on the board
GNDA: C16.2, C21.2, C23.2, C26.2; also elsewhere on the board
unnamed: D3.2 (A), R5.1
unnamed: D4.2 (A), R15.1
unnamed: D5.2 (A), R18.1
unnamed: D6.2 (A), R21.1
unnamed: J1.2, R24.2
unnamed: J1.3, R25.2
unnamed: J5.4, R19.2
unnamed: J5.5, R20.2
unnamed: J5.6, R22.2
unnamed: J5.7, R23.2
unnamed: J6.2, R16.2
unnamed: J6.3, R17.2
unnamed: C25.1, JP1.1 (A)
unnamed: J6.5, JP1.2 (B)
unnamed: R26.2, U8.40 ((PCINT8/T0/XCK)PB0)
unnamed: C21.1, C23.1, U8.29 (AREF)
unnamed: C17.1, U8.8 (XTAL1), Y1.3
unnamed: C15.1, U8.7 (XTAL2), Y1.1
PA0: U8.37 ((PCINT0/ADC0)PA0); also elsewhere on the board
PA1: U8.36 ((PCINT1/ADC1)PA1); also elsewhere on the board
SCL_RPM: J1.4, JP2.1 (A); also elsewhere on the board
SDA_RPM: J1.5, JP3.1 (A); also elsewhere on the board

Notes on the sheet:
VTG
MISO
SCL
Default addr 0x44
MOSI
SDA
Payload bus port
Connect PCF8583 to ATmega bus
Debug & Programming port
SCK
Pixhawk UART&I2C port
Addres 0x58

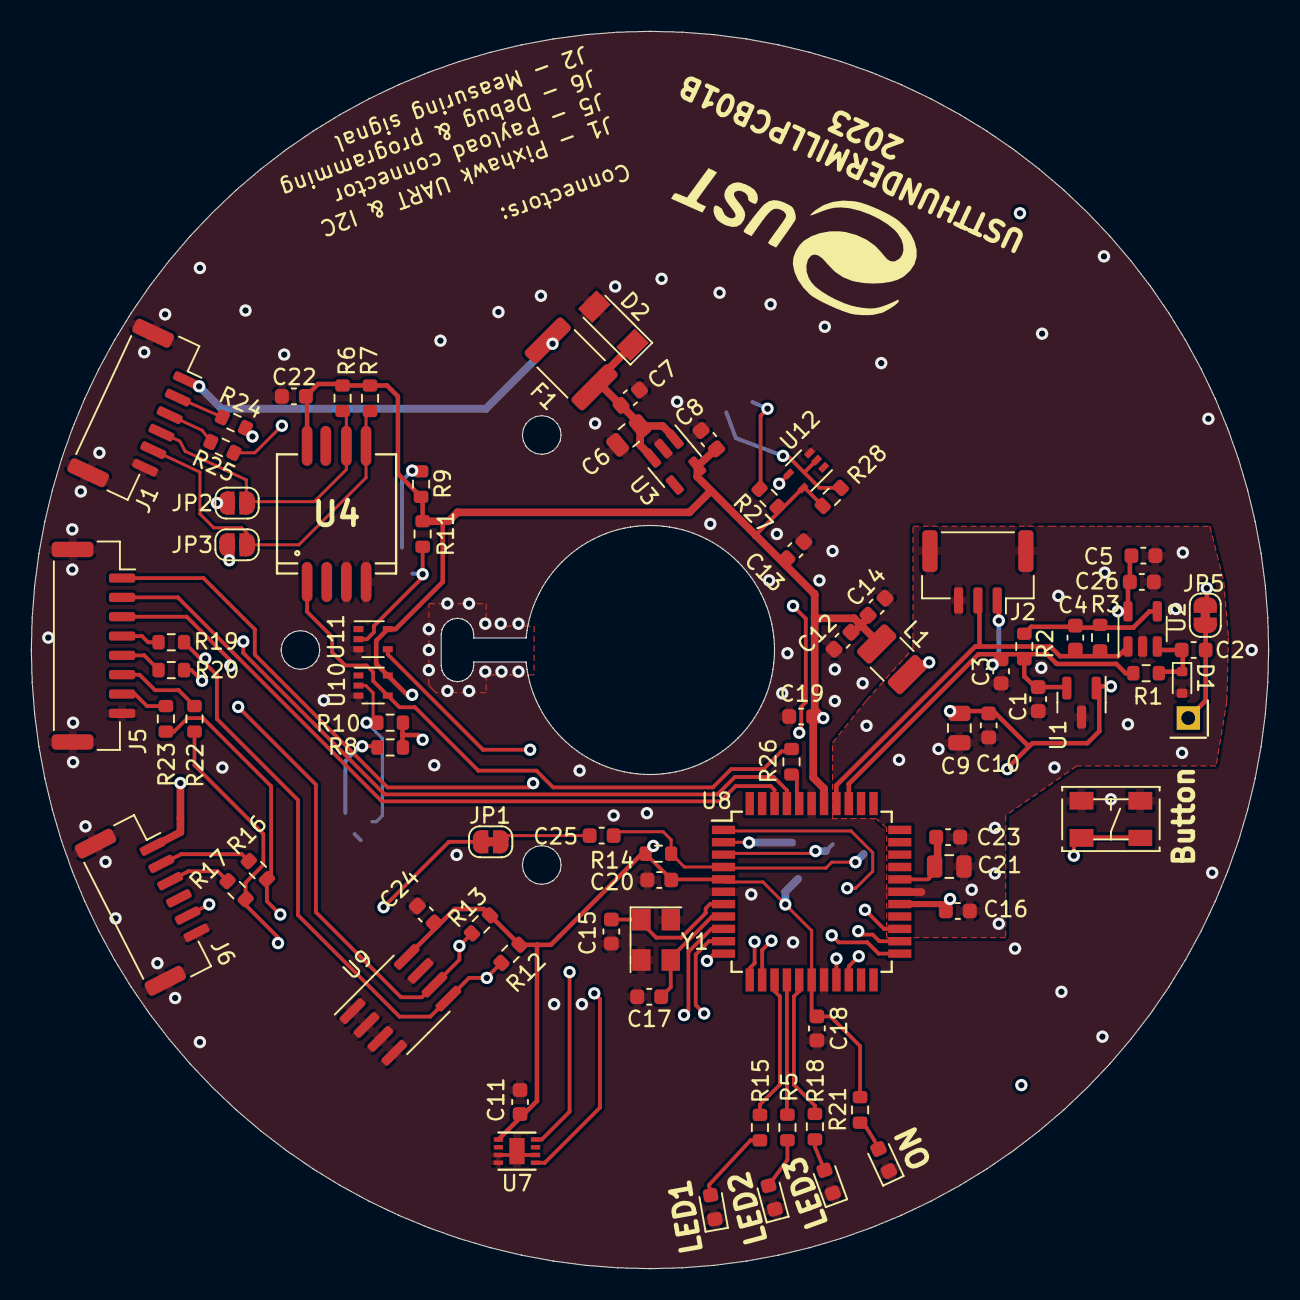
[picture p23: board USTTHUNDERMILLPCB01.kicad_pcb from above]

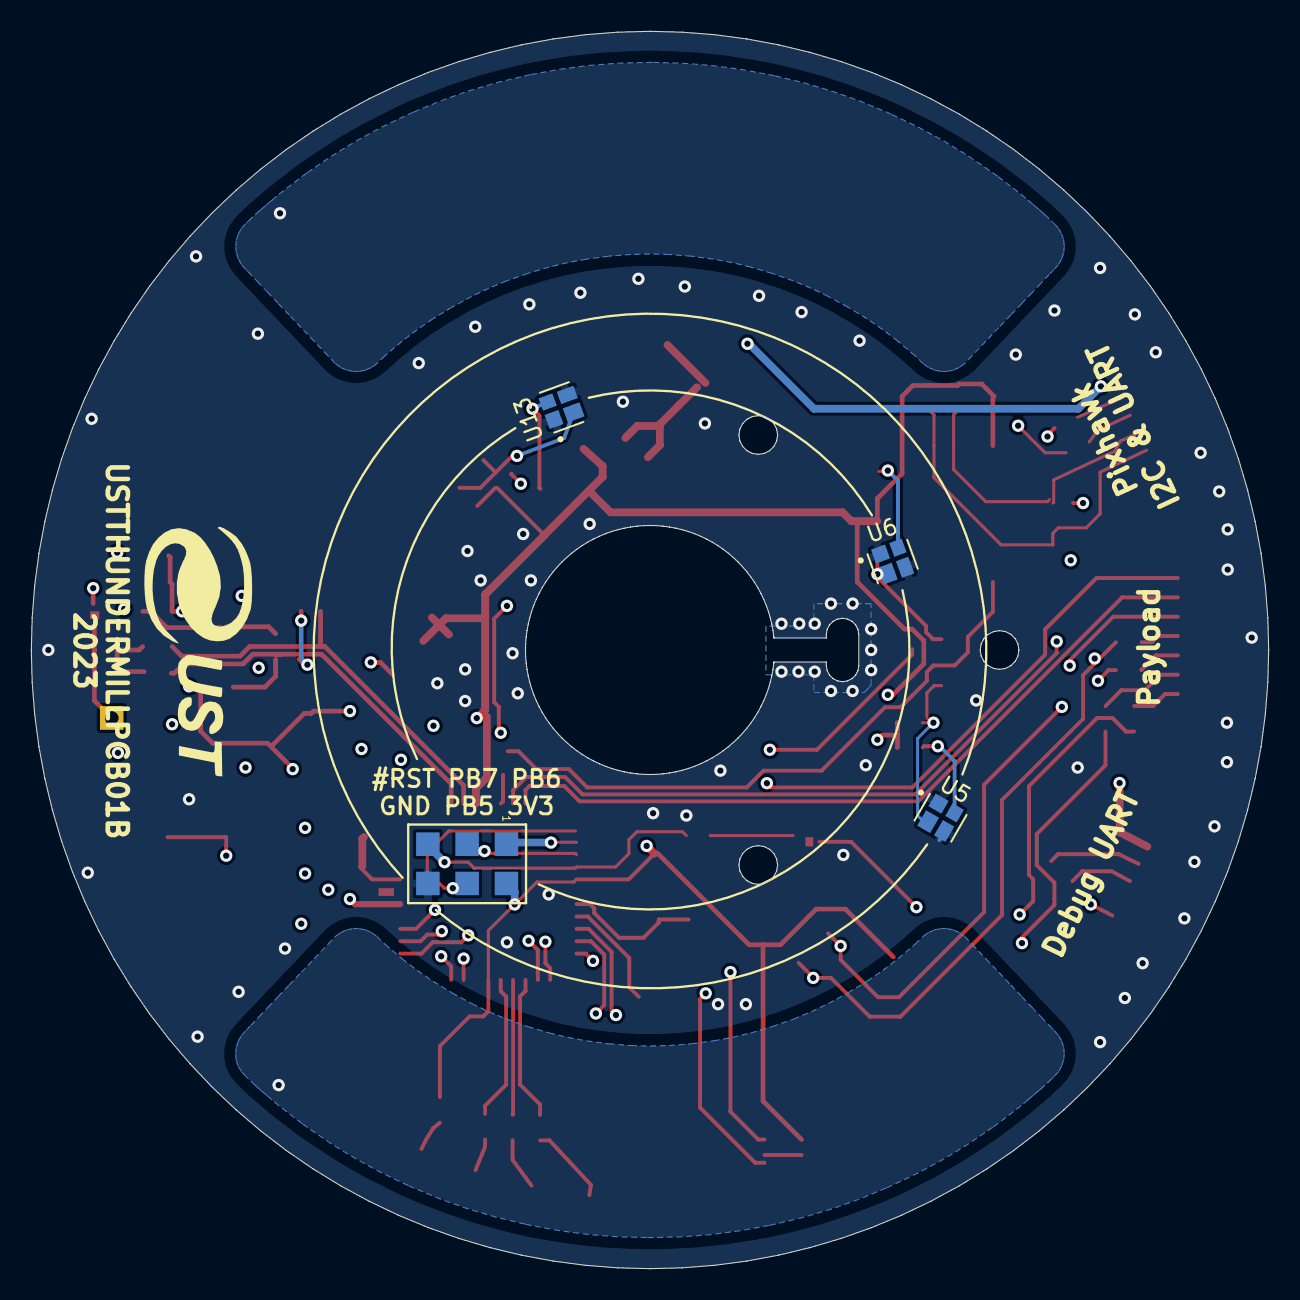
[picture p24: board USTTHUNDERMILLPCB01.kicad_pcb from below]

Board: 4 copper layers, 80.0 x 80.0 mm, 89 parts (5 on the bottom side), 57 nets.

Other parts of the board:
G1, G2: UST

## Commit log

2023-06-13 Update actions products
    [USTTHUNDERMILLPCB01-B_Cu.gbr, USTTHUNDERMILLPCB01-B_Mask.gbr, USTTHUNDERMILLPCB01-B_Paste.gbr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]
2023-07-04 Editing component values
    [CPU.kicad_sch, tachometer.kicad_sch]
2023-07-04 Editing F. and B.FAB
    [USTTHUNDERMILLPCB01.kicad_pcb]
2023-11-04 Updated title block.
    [CPU.kicad_sch, USTTHUNDERMILLPCB01.kicad_sch, tachometer.kicad_sch]
2025-02-15 Update project to KiCADv8.
    [CPU.kicad_sch, USTTHUNDERMILLPCB01.csv, USTTHUNDERMILLPCB01.kicad_sch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]
